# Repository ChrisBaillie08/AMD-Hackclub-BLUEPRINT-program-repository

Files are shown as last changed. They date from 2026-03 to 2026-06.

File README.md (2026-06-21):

 # AMD-Hackclub-BLUEPRINT-program-repository
**Description**
This project is a DIY analog synthesiser that I have designed from scratch as an EPQ project. It is a dual oscillator monophonic synthesiser with entirely analog signal processing.
A RP Pico and DAC is used to convert MIDI data into control voltages for velocity and pitch.

The synthesiser includes an analog velocity sensitive envelope, using mathematical models of how real world piano tones behave to model the relationship between note velocity and max amplitude, attack time, decay time and release time.

Additional features include a LFO with sineshaper, two oscillators, a powerful 4 pole VCF and a digital transposition section, which allows each oscillator to be tuned up and down in semitone increments.

**How do I use this synthesiser?**
If anyone is, for whatever reason, keen to emulate this project and try it out, you will find that it functions mostly like any analog synth you might have used before. The signal chain starts with an oscillator, which produces selectable saw/triangle/pulse waves at a frequency defined by a control voltage. This control voltage comes from a DAC, driven by my RP Pico running MIDI - CV conversion. Next, this waveform, rich in harmonics, runs through a mixer, where the level of each waveform, as well as those on the duplicate 2nd oscillator, can be adjusted. These waveforms are summed and sent into a VCF, or voltage controlled filter. This uses a 4 pole filter, meaning essentially 4 filters in series, to suppress higher harmonics. The frequency at which harmonics are cut off, called the cutoff frequency, can be adjusted on the panel, or by a control voltage. This control voltage comes from and envelope, which I will explain in a bit. The VCF also does some other things like boost the frequency at cutoff (resonance), and then we get to the VCA, or Voltage Controlled Amplifier. One channel of this is used to attenuate the signal, again with both a master output volume and a voltage control from an envelope. Furthermore, there is a LFO, or low frequency oscillator, operating at sub audio frequencies, whose output can be used to modulate the frequency of the oscillator, creating a vibrato like effect. This has a cool sine shaper, used to derive a sinosuidal profile wave from a triangle wave using the non linear distortion of a LM13700 dual transconductance op amp. Now, to the envelopes. In my synthesiser, unlike most, there are two ways to operate the envelopes: Manual and Velocity sensitive. In manual, user controlled levels of attack, decay and release time as well as sustain level define the profile of an ADSR envelope. To help understand this, here is a little graphic of the profile of the control voltage this produces, which can be sent to the VCA or VCF to cause the cutoff/amplitude to rise then fall over the course of a note being pressed:
https://www.google.com/url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
In Velocity Senstive mode, things get a little bit more interesting. My RP Pico is running a parallel process of outputting a Velocity CV, which is proportional to the note velocity MIDI Value. This Velocity CV is sent to a series of logarithmic amplifiers and inverting amplifiers in what I call the piano-ifier. The purpose of this section is to emulate how real piano tones' decay, attack and release times relate to note velocity. For example, decay time follows a linear relationship, whilst release time is a logarithmic one. In addition, one of the channels of the VCA is used as a master max amplitude attenuator, where the loudness/amplitude of the signal is controlled proportional to note velocity, as seen on real pianos. 
The form of the casing of the synthesiser is roughly modelled of a MiniMoog, a classic 1970s synthesiser. This will be updated and iterated on in the future as my EPQ research dives into retrofuturism after the deadline of Hackclub.

W**hy did I decide to do this project?**
This is for an EPQ qualification, where I design an artefact whilst documenting my research, design and prototyping in detail. I chose this specific artefact as it stems from a curiosity into electronic music, and vintage synthesisers which I never really looked into before. My research has taken me across several different technical areas, as this is no ordinary synthesiser. In addition, I have always wanted to get to grips with designing electronic schematics, which I know is a good skill to have. This led me to choose an analog synthesiser, which uses mostly analog circuitry in creative ways to result in the synthesis of sound, with a digital MIDI-CV converter, which on its own cannot be understated.

**COST OPTIMISATION: Please Read For Blueprint**
For the cost optimisation process, I changed as many components as I could to aliexpress or to digikey, which was much cheaper than my previous suppliers in the UK. As part of my revision, I was recommended to use LCSC for components, however in my location the price of shipping would have made this even more expensive, given I have free shipping from my Current Mouser and Digikey orders. In addition, I did try to source every component on LCSC or Aliexpress, however so many of my components, many of which are quite niche, were simply not offered by these sites, such as specific film capacitors and resistors. As part of my cost optimisation, I also removed all the components from switch Electronics, who charge quite a lot for the components they are offering. It was also suggested that I should buy resistors in larger packs for cheaper unit cost. Whilst this would be very effective if I was buying a large quantity of a few different components, the nature of my project demands that unfortunately I often only need one resistor of a specific value with low tolerance, and this ends up being way more cost effective to buy a £0.08 single resistor than drop more money on a bulk pack, and only use a single one of them. As such, due to the difficult nature of this cost optimisation, I have not been able to reduce the price by a massive amount. I have cancelled any plans to use PCBs as these would require more money and be impractical prototyping-wise. If there are any modifications I should do in order to upgrade this into a Tier 1 Project, please don't hesitate to ask me to resubmit the project with more detail/complexity. I am completing this as part of an EPQ project, and as such the project is at the standard of, if not definitely above, what is required for an assessed project qualification worth half an A level. Not all the process of design has been detailed here in my ReadMe, but I have created an extensive log describing everything I have done so far, as this project is more complex than it may seem at first glance.

**N.B.** Please bear in mind that this repo will be updated with future development/prototyping. If this project looks incomplete or not sufficiently designed, please know that for something of this complexity, the timescales don't perfectly align with Hackclub deadlines, but for my EPQ project I still have time left in my research phase. Furthermore, the nature of DIY analog synthesisers is that no matter how much time you spend on a schematic, there will always be an element of just seeing what works on a physical prototype, so much revision and iteration will be needed. That being said, I am confident in my design as it stands right now. The most important thing is that I know get to building things to start testing which modules work. 

**Schematic**
Here is a screenshot of my current KiCad schematic. There are no PCBs required at this stage as I need to test everything on breadboards first, and I will probably just use protoboards in the end.


**3D Model**
Here are some screenshots of my current 3D model, designed in Fusion 360. 








**BOM**
Here is my BOM, in table format (markdown). Note that the prices are in GBP (£)

| Name | Quantity | Unit Price | Extended Price GBP | Manufacturer Part Number | Link |
| --- | --- | --- | --- | --- | --- |
| SSI2131 VCO IC | 3 | £3.35 | £10.05 | | https://www.thonk.co.uk/shop/sound-semiconductor/ |
| SSI2164 Quad VCA | 1 | £3.80 | £3.80 | | https://www.thonk.co.uk/shop/sound-semiconductor/ |
| SSI2144 LP VCF | 1 | £3.75 | £3.75 | | https://www.thonk.co.uk/shop/sound-semiconductor/ |
| 400Ω Resistor | 4 | £0.16 | £0.63 | | https://www.mouser.co.uk/ProductDetail/YAGEO/MFR-25FTF52-400R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 |
| 4.9kΩ Resistor | 1 | £0.14 | £0.14 | | https://www.mouser.co.uk/ProductDetail/YAGEO/MFR-12FTF52-4K9?qs=sGAEpiMZZMtlubZbdhIBIOunD5kldQozQZhToFOhuP4%3D |
| 40kΩ Resistor | 1 | £0.14 | £0.14 | | https://www.mouser.co.uk/ProductDetail/YAGEO/MFR-12FTF52-40K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 |
| 6.8nF Unpolarized Capacitor | 3 | £0.43 | £1.30 | | https://www.mouser.co.uk/ProductDetail/Vishay/564R20GAD68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 |
| 100pF Unpolarized Film Capacitor | 2 | £0.39 | £0.78 | | https://www.mouser.co.uk/ProductDetail/Vishay-Roederstein/KP1830110634?qs=2ImG92Kq1uw%2FOFeuXoLUsQ%3D%3D |
| 22.1kΩ Resistor | 3 | £0.58 | £1.73 | | https://www.mouser.co.uk/ProductDetail/Vishay-Dale/CMF5522K100FHEB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 |
| 4.99kΩ Resistor | 1 | £0.97 | £0.97 | | https://www.mouser.co.uk/ProductDetail/Vishay-Dale/CMF504K9900FHEB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 |
| 162kΩ Resistor | 1 | £0.23 | £0.23 | | https://www.mouser.co.uk/ProductDetail/Vishay-Dale/CCF55162KFKE36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 |
| 910Ω Resistor | 1 | £0.23 | £0.23 | | https://www.mouser.co.uk/ProductDetail/Vishay-Dale/CCF07910RGKE36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 |
| 750Ω Resistor | 2 | £0.23 | £0.45 | | https://www.mouser.co.uk/ProductDetail/Vishay-Dale/CCF07750RJKE36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 |
| 30kΩ Resistor | 2 | £0.23 | £0.45 | | https://www.mouser.co.uk/ProductDetail/Vishay-Dale/CCF0730K0GKE36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 |
| 40nF unpolarized Cap | 1 | £2.44 | £2.44 | | https://www.mouser.co.uk/ProductDetail/Vishay-Cera-Mite/565RZ5UBA102EU403M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 |
| 5.1kΩ Resistor | 1 | £0.63 | £0.63 | | https://www.mouser.co.uk/ProductDetail/Vishay-Beyschlag/MBE04140C5101FR200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 |
| 1.2MΩ Resistor | 1 | £0.38 | £0.38 | | https://www.mouser.co.uk/ProductDetail/Vishay-BC-Components/VR37000001204JA100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 |
| 499kΩ Resistor | 2 | £0.19 | £0.37 | | https://www.mouser.co.uk/ProductDetail/Vishay-BC-Components/VR25000004993FA100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 |
| 26.7Ω Resistor | 1 | £0.19 | £0.19 | | https://www.mouser.co.uk/ProductDetail/Vishay-BC-Components/SFR25H0002679FR500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 |
| 267Ω Resistor | 3 | £0.17 | £0.50 | | https://www.mouser.co.uk/ProductDetail/Vishay-BC-Components/SFR2500002670FR500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 |
| 82kΩ Resistor | 1 | £0.28 | £0.28 | | https://www.mouser.co.uk/ProductDetail/Vishay-BC-Components/PR02000208202JR500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 |
| 499Ω Resistor | 6 | £0.32 | £1.89 | | https://www.mouser.co.uk/ProductDetail/Vishay-BC-Components/PR01000104990FA100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 |
| 20kΩ Resistor | 1 | £0.66 | £0.66 | | https://www.mouser.co.uk/ProductDetail/Vishay-BC-Components/PR01000102002JA100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 |
| 20kΩ Resistor | 2 | £0.33 | £0.66 | | https://www.mouser.co.uk/ProductDetail/Vishay-BC-Components/PR01000102002JA100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 |
| 200Ω Resistor | 2 | £0.68 | £1.37 | | https://www.mouser.co.uk/ProductDetail/Vishay-BC-Components/MBE04140C2000DC100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 |
| 68.1kΩ Resistor | 1 | £0.28 | £0.28 | | https://www.mouser.co.uk/ProductDetail/Vishay-BC-Components/MBB0207IC6812FCT00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 |
| 70kΩ Resistor | 1 | £0.28 | £0.28 | | https://www.mouser.co.uk/ProductDetail/Vishay-BC-Components/MBB02070C7002FCT00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 |
| 10uF Unpolarized Capacitor | 2 | £1.68 | £3.36 | | https://www.mouser.co.uk/ProductDetail/Vishay-BC-Components/MAL202129109E3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 |
| 560pF Unpolarized PS Capacitor | 2 | £1.81 | £3.62 | | https://www.mouser.co.uk/ProductDetail/Vishay-BC-Components/BFC237546561?qs=kL1ClTr6oBqT2w76ajcAjg%3D%3D |
| Tl074 Quad Op-Amps | 10 | £0.59 | £5.88 | | https://www.mouser.co.uk/ProductDetail/Texas-Instruments/TL074ACN?qs=IEl3ej0IqwCwHW3RmzQ1ew%3D%3D |
| TL072 Dual Op Amps | 14 | £0.56 | £7.87 | | https://www.mouser.co.uk/ProductDetail/Texas-Instruments/TL072CP?qs=5nGYs9Do7G3e6Tx9uHIgUA%3D%3D |
| TL071 Single Op Amp | 6 | £0.35 | £2.08 | | https://www.mouser.co.uk/ProductDetail/Texas-Instruments/TL071CP?qs=3FVjRv9mUZ%2FN1XJT5coqUQ%3D%3D |
| LM385BYZ-2.5 | 1 | £1.50 | £1.50 | | https://www.mouser.co.uk/ProductDetail/Texas-Instruments/LM385BYZ-2.5-NOPB?qs=QbsRYf82W3HrBcCF05YkkQ%3D%3D |
| 43Ω Resistor | 1 | £0.30 | £0.30 | | https://www.mouser.co.uk/ProductDetail/TE-Connectivity-Neohm/4-2176791-8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 |
| LM7905CV LDO | 1 | £0.41 | £0.41 | | https://www.mouser.co.uk/ProductDetail/STMicroelectronics/L7905CV?qs=bZskSr8d5Y8JqSs%2FnmNLHA%3D%3D |
| 3.9nF Unpolarized Cap | 1 | £0.68 | £0.68 | | https://www.mouser.co.uk/ProductDetail/Panasonic/ECW-H8392JV?qs=doAwqMPOn2u2n6YE8ICUYw%3D%3D |
| 7809 Voltage converter | 1 | £0.41 | £0.41 | | https://www.mouser.co.uk/ProductDetail/onsemi/MC7809CTG?qs=%252B9%2Fcbd0IE0RZOsET7SgWUA%3D%3D |
| 1.2 nF Unpolarized Cap | 1 | £0.47 | £0.47 | | https://www.mouser.co.uk/ProductDetail/Murata-Electronics/RDE5C2A122J0P1H03B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 |
| MCP1700-2702E/TO | 1 | £0.41 | £0.41 | | https://www.mouser.co.uk/ProductDetail/Microchip-Technology/MCP1700-2702E-TO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 |
| Gravity I2C Dual Channel DAC 15 Bit DFR1073 | 1 | £11.18 | £11.18 | | https://www.mouser.co.uk/ProductDetail/DFRobot/DFR1073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 |
| 10k Log Slide Potentiometer | 6 | £2.09 | £12.54 | | https://www.mouser.co.uk/ProductDetail/Bourns/PTA6044-2015DPA103?qs=U%2FacTlguYxZvBk%2FzeZBsew%3D%3D |
| 10k Linear Slide Potentiometer | 2 | £1.93 | £3.86 | | https://www.mouser.co.uk/ProductDetail/Bourns/PTA6043-2215DPB103?qs=QARuOjD9jaExli%252Bh5UpR0g%3D%3D |
| 1MΩ Potentiometer | 1 | £1.70 | £1.70 | | https://www.mouser.co.uk/ProductDetail/Bourns/PDB181-GTR01-105A2?qs=U%2FacTlguYxYr2ecQgPe%2FHA%3D%3D |
| 300Ω Trimmer Resistors | 2 | £0.68 | £1.35 | | https://www.mouser.co.uk/ProductDetail/Bourns/3362P-1-301LF?qs=78XbCJDlDc20qxrEQi%252BtUQ%3D%3D |
| Rotary Encoder Dual Channel | 2 | £2.23 | £4.46 | | https://www.mouser.co.uk/ProductDetail/Alps-Alpine/EC12E24404A8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 |
| MCP4131 | 2 | £0.72 | £1.44 | | https://www.google.com/url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 |
| IC ADC 8BIT 20-SOIC | 1 | £6.55 | £6.55 | ADC0804LCWMX/NOPB | https://www.digikey.co.uk/short/bf98020b |
| RES ARRAY 8 RES 10K OHM 16DIP | 3 | £2.05 | £6.16 | 4116R-1-103FLF | https://www.digikey.co.uk/short/bf98020b |
| CAP CER 0.1UF 50V X7R RADIAL | 38 | £0.14 | £5.20 | K104K10X7RF53L2 | https://www.digikey.co.uk/short/bf98020b |
| SMT ADAPTERS 3 PACK 20SOIC/TSSOP | 1 | £4.01 | £4.01 | 1206 | https://www.digikey.co.uk/short/bf98020b |
| TRIMMER 300 OHM 0.5W PC PIN TOP | 2 | £1.37 | £2.74 | 3362P-1-301LF | https://www.digikey.co.uk/short/bf98020b |
| TRIMMER 5K OHM 0.5W PC PIN SIDE | 2 | £1.36 | £2.71 | 3362W-1-502LF | https://www.digikey.co.uk/short/bf98020b |
| CAP FILM 100PF 10% 400VDC RAD | 5 | £0.48 | £2.40 | FKP2G001001D00KSSD | https://www.digikey.co.uk/short/bf98020b |
| CAP CER 10UF 50V X7S RADIAL | 2 | £1.10 | £2.21 | FK20X7S1H106KR000 | https://www.digikey.co.uk/short/bf98020b |
| CAP CER 1UF 6.3V X5R RADIAL | 12 | £0.14 | £1.73 | FK18X5R0J105KN020 | https://www.digikey.co.uk/short/bf98020b |
| TRIMMER 500KOHM 0.1W PC PIN SIDE | 3 | £0.50 | £1.51 | PT6KH-504B2020 | https://www.digikey.co.uk/short/bf98020b |
| LED AMBER DIFFUSED T-1 3/4 T/H | 12 | £0.12 | £1.43 | LTL-307A | https://www.digikey.co.uk/short/bf98020b |
| RES 10K OHM 1% 1/4W AXIAL | 39 | £0.03 | £1.27 | RNF14FTD10K0 | https://www.digikey.co.uk/short/bf98020b |
| OPTOISOLTR 5KV OPEN COLL 8-DIP | 1 | £1.20 | £1.20 | 6N137 | https://www.digikey.co.uk/short/bf98020b |
| TRIMMER 500KOHM 0.15W PC PIN TOP | 3 | £0.40 | £1.19 | PT10MV10-504A1010-S | https://www.digikey.co.uk/short/bf98020b |
| FILM CAP MKT BOX 1.UF 10% 63VDC | 2 | £0.58 | £1.15 | B32529C0105K006 | https://www.digikey.co.uk/short/bf98020b |
| 1/4" PHONE STEREO VERTICAL SLD S | 1 | £1.09 | £1.09 | ACJS-MVS-5 | https://www.digikey.co.uk/short/bf98020b |
| RES 100K OHM 1% 1/6W AXIAL | 38 | £0.03 | £1.08 | MFR-12FTF52-100K | https://www.digikey.co.uk/short/bf98020b |
| TRIMMER 100KOHM 0.1W PC PIN SIDE | 2 | £0.49 | £0.98 | PT6KH-104A1010-PM | https://www.digikey.co.uk/short/bf98020b |
| TRIMMER 1M OHM 0.15W PC PIN SIDE | 2 | £0.44 | £0.89 | PT10LH01-105A2020-PM-S | https://www.digikey.co.uk/short/bf98020b |
| CAP FILM 1.2UF 5% 450VDC RADIAL | 1 | £0.82 | £0.82 | ECW-FD2W125J | https://www.digikey.co.uk/short/bf98020b |
| RES ARRAY 5 RES 10K OHM 10SIP | 2 | £0.36 | £0.72 | 4610X-102-103LF | https://www.digikey.co.uk/short/bf98020b |
| RES NTWRK 16 RES MULT OHM 10SIP | 1 | £0.61 | £0.61 | 4610X-R2R-103LF | https://www.digikey.co.uk/short/bf98020b |
| CAP FILM 220PF 10% 400VDC RAD | 1 | £0.48 | £0.48 | FKP2G002201D00KSSD | https://www.digikey.co.uk/short/bf98020b |
| RES 1K OHM 1% 0.6W AXIAL | 5 | £0.08 | £0.42 | LR1F1K0 | https://www.digikey.co.uk/short/bf98020b |
| CAP ALUM 47UF 20% 50V RADIAL TH | 1 | £0.26 | £0.26 | 50YXJ47M6.3X11 | https://www.digikey.co.uk/short/bf98020b |
| CAP FILM 3900PF 5% 63VDC RADIAL | 1 | £0.26 | £0.26 | B32529C0392J000 | https://www.digikey.co.uk/short/bf98020b |
| CAP FILM 0.047UF 5% 100VDC RAD | 1 | £0.26 | £0.26 | R82EC2470AA60J | https://www.digikey.co.uk/short/bf98020b |
| IC REG LINEAR 9V 100MA TO92-3 | 1 | £0.26 | £0.26 | L78L09ACZ-TR | https://www.digikey.co.uk/short/bf98020b |
| IC REG LINEAR 12V 100MA TO92-3 | 1 | £0.25 | £0.25 | L78L12ACZ | https://www.digikey.co.uk/short/bf98020b |
| CAP ALUM 100UF 20% 35V RADIAL TH | 1 | £0.20 | £0.20 | 860040573004 | https://www.digikey.co.uk/short/bf98020b |
| RES 1M OHM 1% 0.6W AXIAL | 2 | £0.08 | £0.17 | LR1F1M0 | https://www.digikey.co.uk/short/bf98020b |
| DIODE GEN PURP 50V 1A DO204AC | 1 | £0.12 | £0.12 | 1N4001 | https://www.digikey.co.uk/short/bf98020b |
| DIODE STANDARD 100V 200MA DO35 | 1 | £0.08 | £0.08 | 1N4148 | https://www.digikey.co.uk/short/bf98020b |
| RES 150K OHM 1% 1/4W AXIAL | 1 | £0.08 | £0.08 | MFR-25FRF52-150K | https://www.digikey.co.uk/short/bf98020b |
| RES 33K OHM 1% 1/4W AXIAL | 1 | £0.08 | £0.08 | MFR-25FTE52-33K | https://www.digikey.co.uk/short/bf98020b |
| RES 2.2K OHM 1% 1/4W AXIAL | 1 | £0.08 | £0.08 | MFR-25FTE52-2K2 | https://www.digikey.co.uk/short/bf98020b |
| RES 4.7K OHM 1% 1/4W AXIAL | 1 | £0.08 | £0.08 | MFR-25FTE52-4K7 | https://www.digikey.co.uk/short/bf98020b |
| RES 40.2K OHM 1% 1/4W AXIAL | 1 | £0.08 | £0.08 | MFR-25FBF52-40K2 | https://www.digikey.co.uk/short/bf98020b |
| RES 26.7K OHM 1% 1/4W AXIAL | 1 | £0.08 | £0.08 | MFR-25FRF52-26K7 | https://www.digikey.co.uk/short/bf98020b |
| Mean Well RT65-C power supply | 1 | £27.00 | £27.00 | | [https://www.amazon.co.uk/Switching-RT-65C-5-Converter-Transformer-Indicator/dp/B0CXJJ38GV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](https://www.amazon.co.uk/Switching-RT-65C-5-Converter-Transformer-Indicator/dp/B0CXJJ38GV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) |
| 230V AC Power entry plug. | 1 | £5.00 | £5.00 | | https://www.amazon.co.uk/Connector-Socket-Illuminated-Switch-Applications/dp/B0FY3FXTFR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 |
| AstroAi Digital Multimeter (Ω, F, V, I, Hz( | 1 | £23.00 | £23.00 | | https://www.amazon.co.uk/AstroAI-Multimeters-Capacitance-Transistors-Temperature/dp/B071JL6LLL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 |
| 7909 Voltage converter | 1 | £2.51 | £2.51 | | https://www.aliexpress.com/p/tesla-landing/index.html?productId=1005010730059732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 |
| LM13700 Ics | 10 | £0.23 | £2.25 | | https://www.aliexpress.com/p/tesla-landing/index.html?productId=1005006784050493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 |
| Amber LED | 10 | £0.18 | £1.80 | | https://www.aliexpress.com/p/tesla-landing/index.html?productId=1005006784050493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 |
| Veroboards | 5 | £0.40 | £1.99 | | https://www.aliexpress.com/item/32844204108.html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 |
| Large Solderless Breadboard | 2 | £11.29 | £22.58 | | https://www.aliexpress.com/item/1005009569771202.html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 |
| 12x18cm Protoboard | 10 | £1.21 | £12.10 | | https://www.aliexpress.com/item/1005006100148769.html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 |
| Jumper wies 120 pcs | 1 | £6.49 | £6.49 | | https://www.aliexpress.com/item/1005003219096948.html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 |
| 10 Metres 22AWG Wire | 1 | £2.91 | £2.91 | | https://www.aliexpress.com/item/1005001980629942.html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 |
                                                                                                                                                                                                                                                                                                                                                                          |                                                                                                                                                                       
| AS3310 VCADSR IC                            | 2        | £8.00      | £16.00             |                          | https://www.thonk.co.uk/shop/alpha-as-series-ic-chips/                                                                                                                                                                                                                                                                                                                                                                                                                                                                                                                                                                                                                                                                                                                                                                                                                                                                                                                                                                                                                                                                                              |
|                                             |          |            |                    |                          |                                                                                                                                                                                                                                                                                                                                                                                                                                                                                                                                                                                                                                                                                                                                                                                                                                                                                                                                                                                                                                                                                                                                                     |
|                                             |          |            | £272.66            |                          |                                                                                                                                                                                                                                                                                                                                                                                                                                                                                                                                                                                                                                                                                                                                                                                                                                                                                                                                                                                                                                                                                                                                                     |

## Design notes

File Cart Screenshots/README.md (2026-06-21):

Mouser Order Screenshots









Digikey Order Screenshots









Thonk Order Screenshots

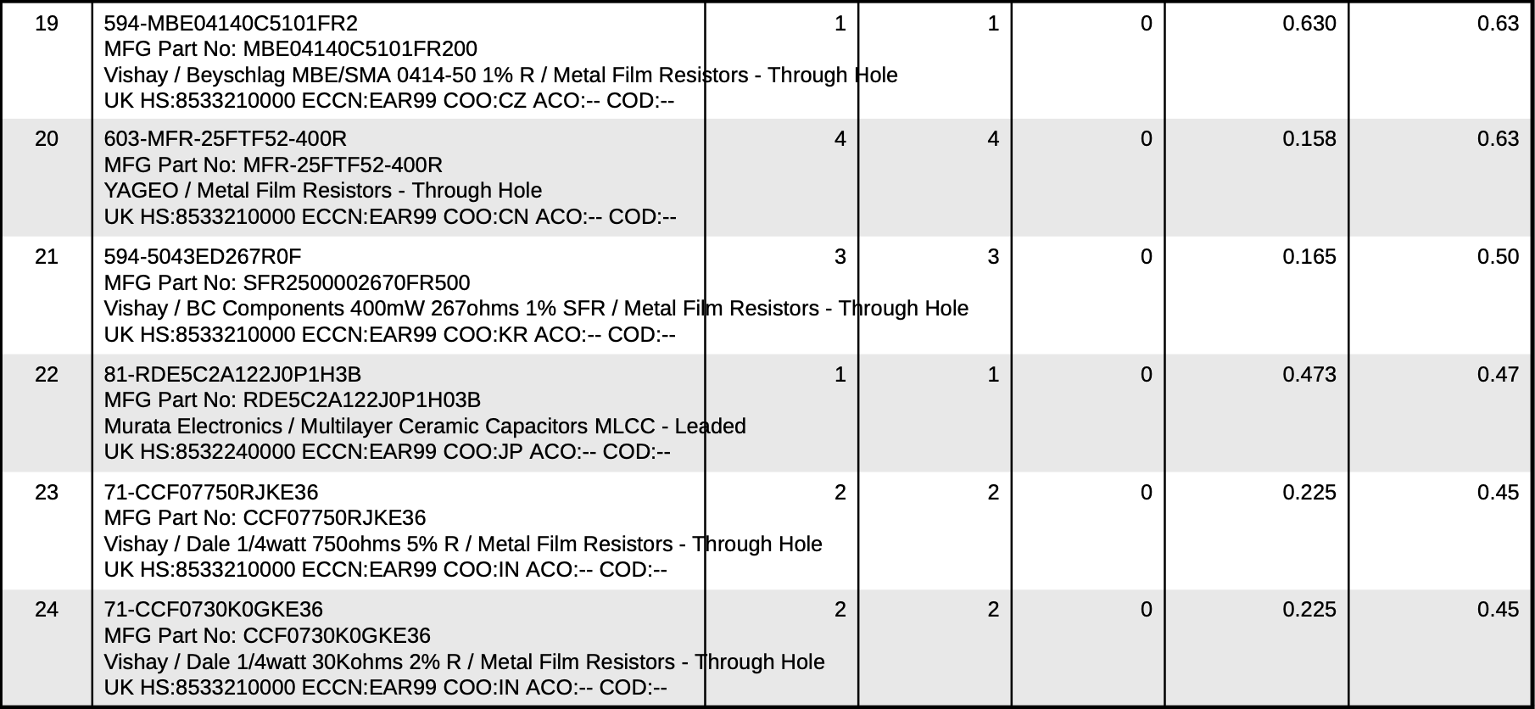
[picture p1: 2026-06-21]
Screenshot 2026-05-15 at 11.04.20.png

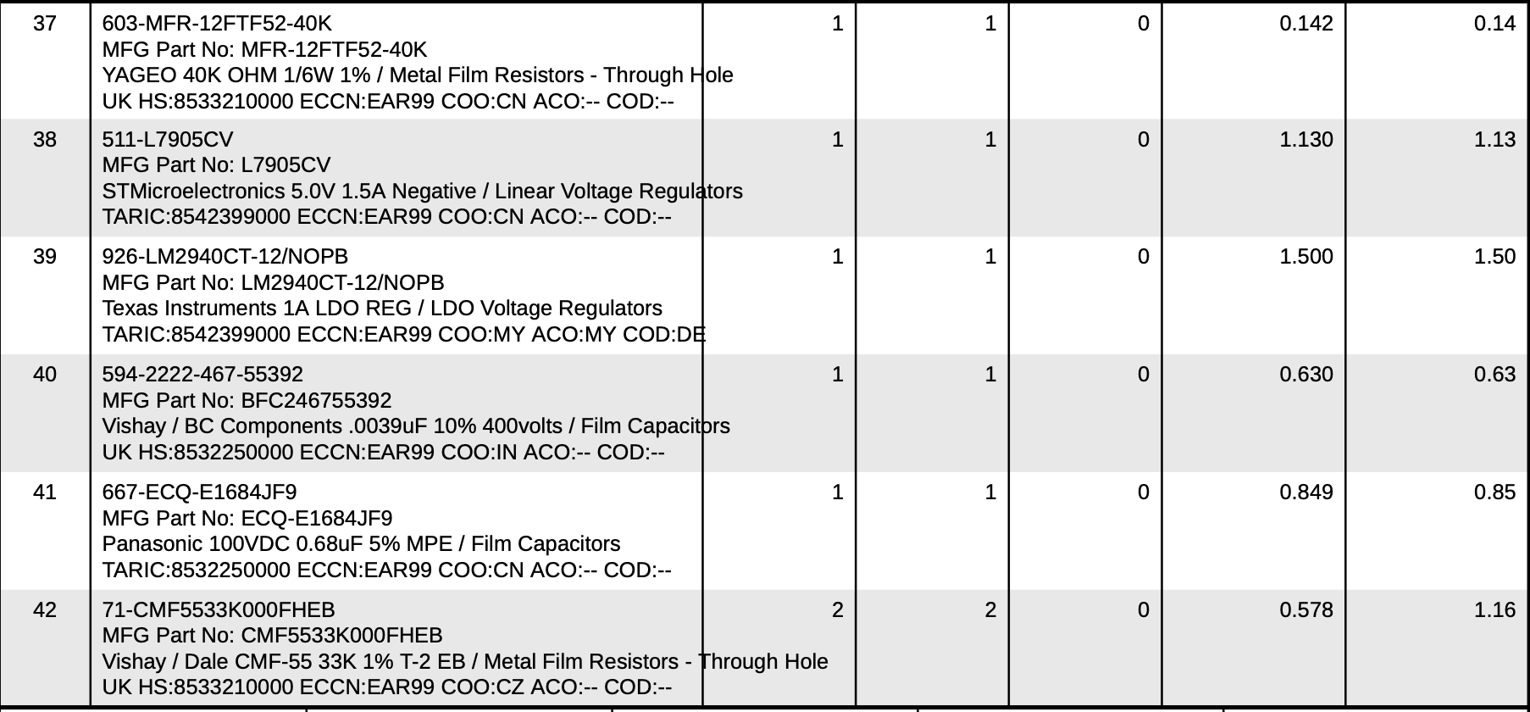
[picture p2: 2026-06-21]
Screenshot 2026-05-15 at 11.04.45.png

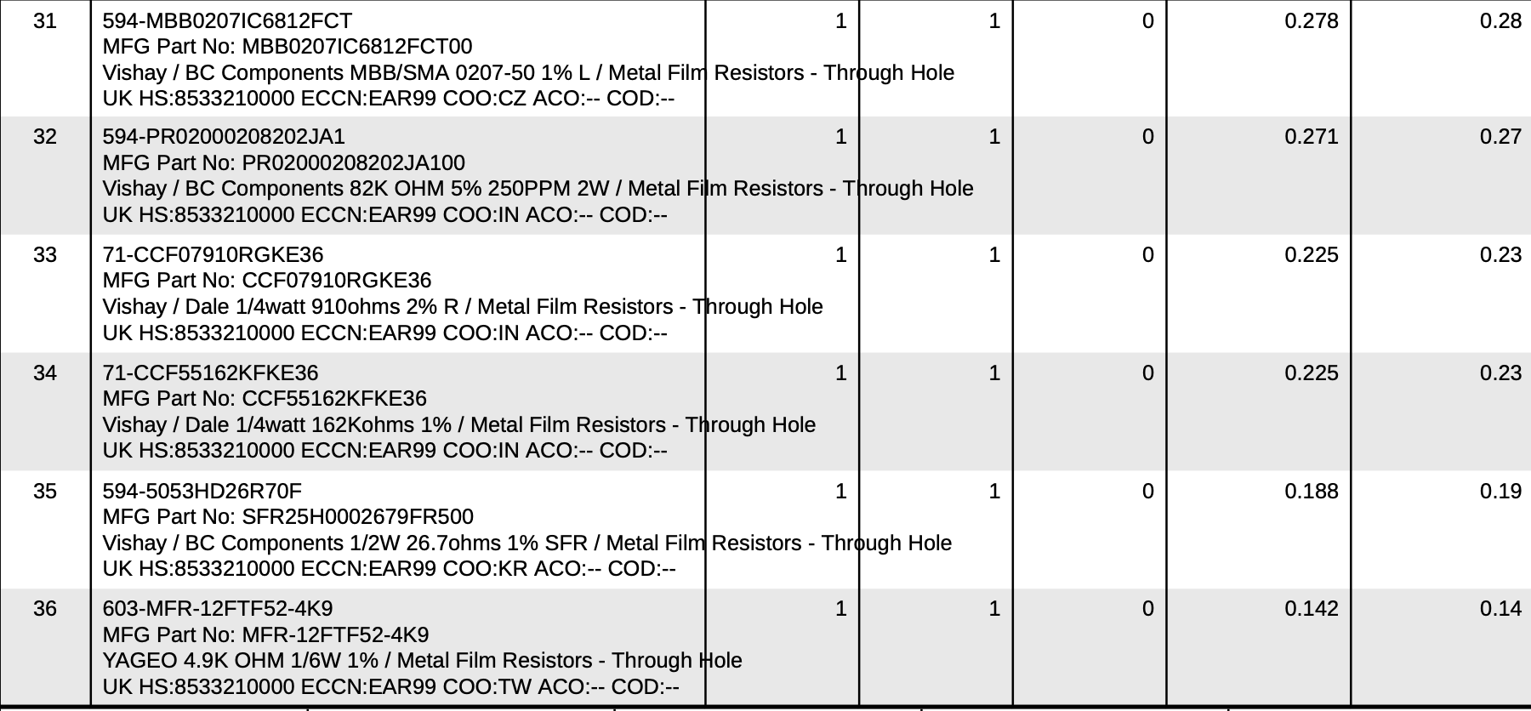
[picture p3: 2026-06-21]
Screenshot 2026-05-15 at 11.04.36.png

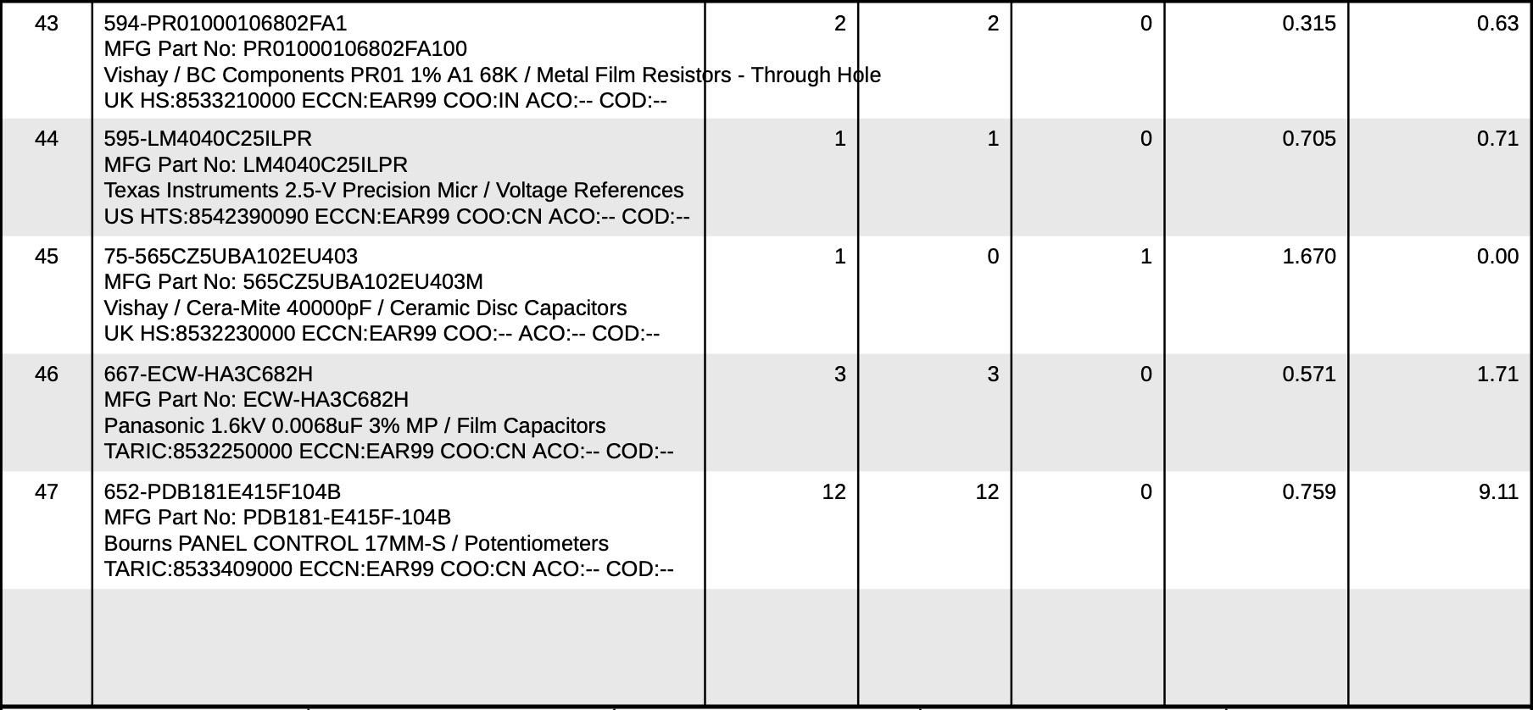
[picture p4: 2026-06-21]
Screenshot 2026-05-15 at 11.05.01.png

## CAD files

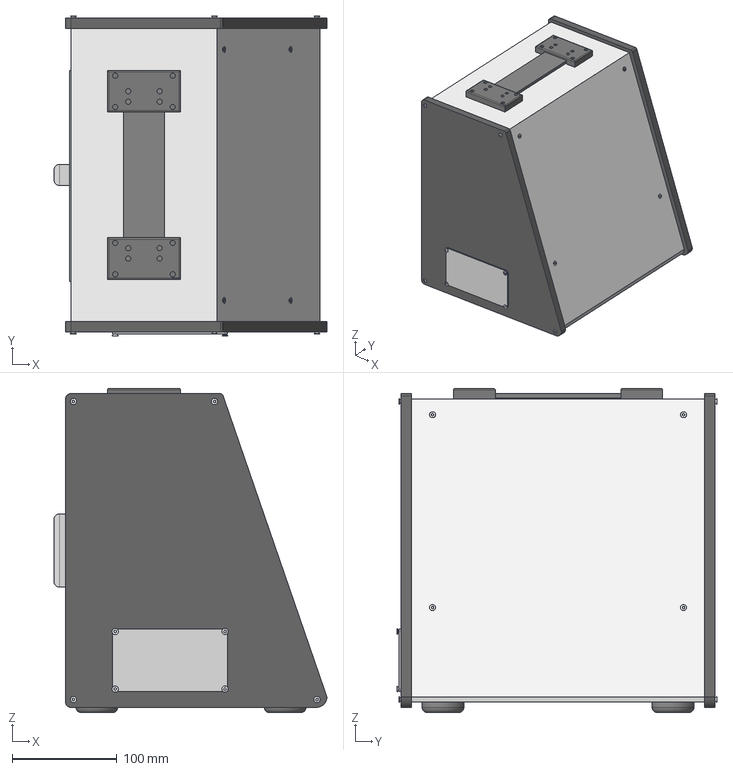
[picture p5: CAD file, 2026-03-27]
Analog Synthesiser Draft 1.step
261.0 x 306.0 x 310.0 mm

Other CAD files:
Analog Synthesiser Draft 1.f3d

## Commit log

2026-03-15 Create CAD Screenshots
2026-03-26 Rename EPQ BOM.csv to BOM.csv
    [BOM.csv, EPQ BOM.csv]
2026-03-27 KiCad File
2026-03-27 .step file for 3D model
    [Analog Synthesiser Draft 1.step]
2026-03-27 .f3d file for 3D Model
    [Analog Synthesiser Draft 1.f3d]
2026-05-13 Create PCB File Information
2026-06-19 Update PCB File Information
